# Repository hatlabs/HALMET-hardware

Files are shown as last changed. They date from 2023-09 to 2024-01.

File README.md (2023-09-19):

# Hat Labs Marine Engine/Tank Interface

This repository contains the Hat Labs Marine Engine/Tank Interface (HALMET) hardware design. HALMET is a powerful microcontroller development board designed for marine environments with a focus on engine and tank monitoring.

HALMET can be used to easily create different types of sensors and control devices for boats. Use scenarios include:

- RPM sensors
- tank level sensors
- bilge sensors
- Engine alarm sensors
- Engine temperature sensors

Since the board has native WiFi and NMEA 2000 compatible CAN bus connectivity, it can be used to create boards with either Signal K or native NMEA 2000 connectivity (or both!).

## Features

The main design features include:

- Built around ESP32, a powerful 32-bit microcontroller with 4 MB of flash
- Wide-range 6-32 V power input with surge protection
- NMEA 2000 compatible CAN interface (4-pin pluggable terminal block screw connector)
- 4 analog inputs with 0-32V input range and 16-bit resolution (2-pin pluggable terminal block screw connectors)
- 4 digital inputs with -32-32V input range, Schmitt triggered logic level threshold at 1.5V (2-pin pluggable terminal block screw connectors)
- 1-Wire interface (3-pin 2.54 mm header)
- I2C interface with both a SparkFun Qwiic connector and a 4-pin 2.54 mm header
- USB interface for programming and serial communication (USB Micro B)
- All above interfaces with proper electromagnetic compatibilty (EMC) design -- the device won't interfere with navigational devices or radio equipment
- All available general-purpose input/output (GPIO) pins broken out to a separate header
- Board designed to fit low-cost waterproof 100x68x50 mm enclosures

Rendering of a version 1.0.0 board:

<!--
Front side.
![Rev. 1.0.0 board](images/pcb_rev_2.0.0.jpg)

Back side.
![Rev. 1.0.0 board bottom side](images/pcb_rev_2.0.0-back.jpg)

-->

## Getting HALMET

HALMET will be available for purchase at the [Hat Labs web store](https://shop.hatlabs.fi/).

## Documentation

HALMET documentation will be available at the [project GitHub Pages](https://docs.hatlabs.fi/halmet/).

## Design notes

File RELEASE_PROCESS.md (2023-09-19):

# JLCPCB release process

## Prerequisites

The release process relies on a [jlc-kicad-tools](https://github.com/matthewlai/JLCKicadTools) script.

To install the script, apply the following commands:
    
    pip3 install git+https://github.com/matthewlai/JLCKicadTools
    pip3 install logzero==1.5.0

## Updating metadata

Create a new release branch, e.g. `release_0.2.0`.

Update page title block for both the schema and the layout (File -> Page Settings).

## Creating assembly files

Create assembly files:

### Eeschema

1. Tools -> Generate Bill of Materials
2. Select any BOM and click Generate (we only need the intermediate XML file).

### Pcbnew

1. File -> Plot -> Plot (Output folder "assembly", otherwise default settings are fine)
2. In the same dialog, Generate Drill Files -> Generate Drill File

3. File -> Fabrication Outputs -> Footprint Position File -> Generate Position File (single file)

### Modifying fabrication files for JLCPCB

On the command line:

    ./fix-jlcpcb-files.sh

## Creating the order

Go to jlcpcb.com -> Order now, and upload `assembly.zip` through the "Add your gerber file" button.

The gerber previewer doesn't always work. 
If that's the case, go to the JLCPCB website File Manager and click on Quote on the uploaded file (once the preview has rendered).

Apply the following selections:

- PCB Qty: (as you wish, there's an extra engineering fee above 10, though)
- Impedance: Yes, JLC7628
- PCB Color: green is usually fastest to manufacture
- Surface Finish: ENIG-RoHS (LeadFree HASL-RoHS might be ok)
- Confirm Production file is recommended
- Remove Order Number: Specify a location

Then select SMT Assembly.

- Assemble top side
- Tooling holes: as you like

Accept the terms and Confirm.

Add BOM File: upload `assembly/HALMET_bom_jlc.csv`
Add CPL File: upload `assembly/HALMET_cpl_jlc.csv`

Select Next.

Verify the parts. For HALMET, there should be only 1 part (the JST SH connector) not selected.
Go through the listing and check that the part type and footprint of uploaded BOM data match the matched part detail. 
This is boring but important!
If any of the parts are out of stock, find a replacement on [https://jlcpcb.com/parts](https://jlcpcb.com/parts) and update the schema and the layout and create fabrication files.
If you're absolutely certain that the layout didn't change, you can just re-upload the BOM and CPL files.

Next.

You're in part placement review.
In principle, JLCPCB pre-inspection catches misrotated parts and fixes the rotation, but I've had an IC be 180° misrotated once. 
So, better check.
The viewer doesn't always work.
If that happens, go back and click the next button again until you see the components.
Go through the layout carefully.

If any of the components are misaligned, check the footprint name in `assembly/HALMET_cpl_jlc.csv`.
Then modify the CPL DB (`cpl_rotations_db.csv`).
Add the footprint regex at the top of the file (but under the header line, of course) with the required rotation adjustment. 
Note that if the footprint matches an existing regex, the new regex should be more specific than the old one, and the rotation adjustment should be in relation to the old one. Note that positive degrees are to the counterclockwise.

If you had to modify the CPL DB, rerun the modification script and reupload the BOM and CPL files.

Once the footprint alignments are correct, you want to Download Unselected Parts list for ordering any missing components from LCSC or elsewhere.
Review the unselected parts list to ensure there are no accidental omissions!
You'll hate yourself if you don't!
Note that if you have assigned LCSC part numbers to the unselected parts, you can upload the file to the LCSC BOM tool to create an order for those parts.

Click "Save to Cart". 
You're done with creating the order.

## Updating the Git repo

After ordering the PCBs:

- Commit the changed files.
- Update the release process documentation, if needed!
- Create a new final commit for the assembly directory contents.
- Finally, create a PR against `main`. 
  This PR should _not_ include `assembly` directory, however. 
  We do not want to have the output files in the main branch.
- Merge the PR and you're done!

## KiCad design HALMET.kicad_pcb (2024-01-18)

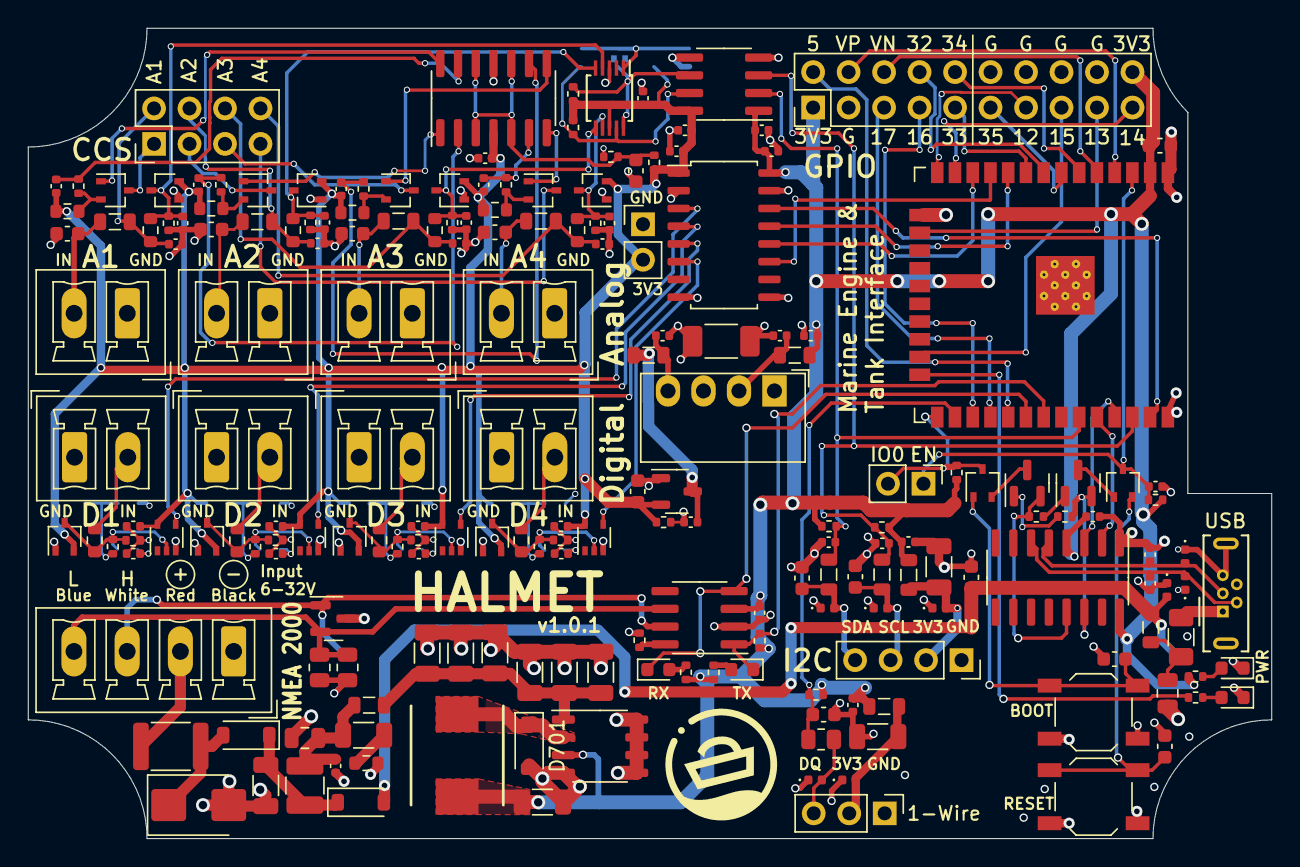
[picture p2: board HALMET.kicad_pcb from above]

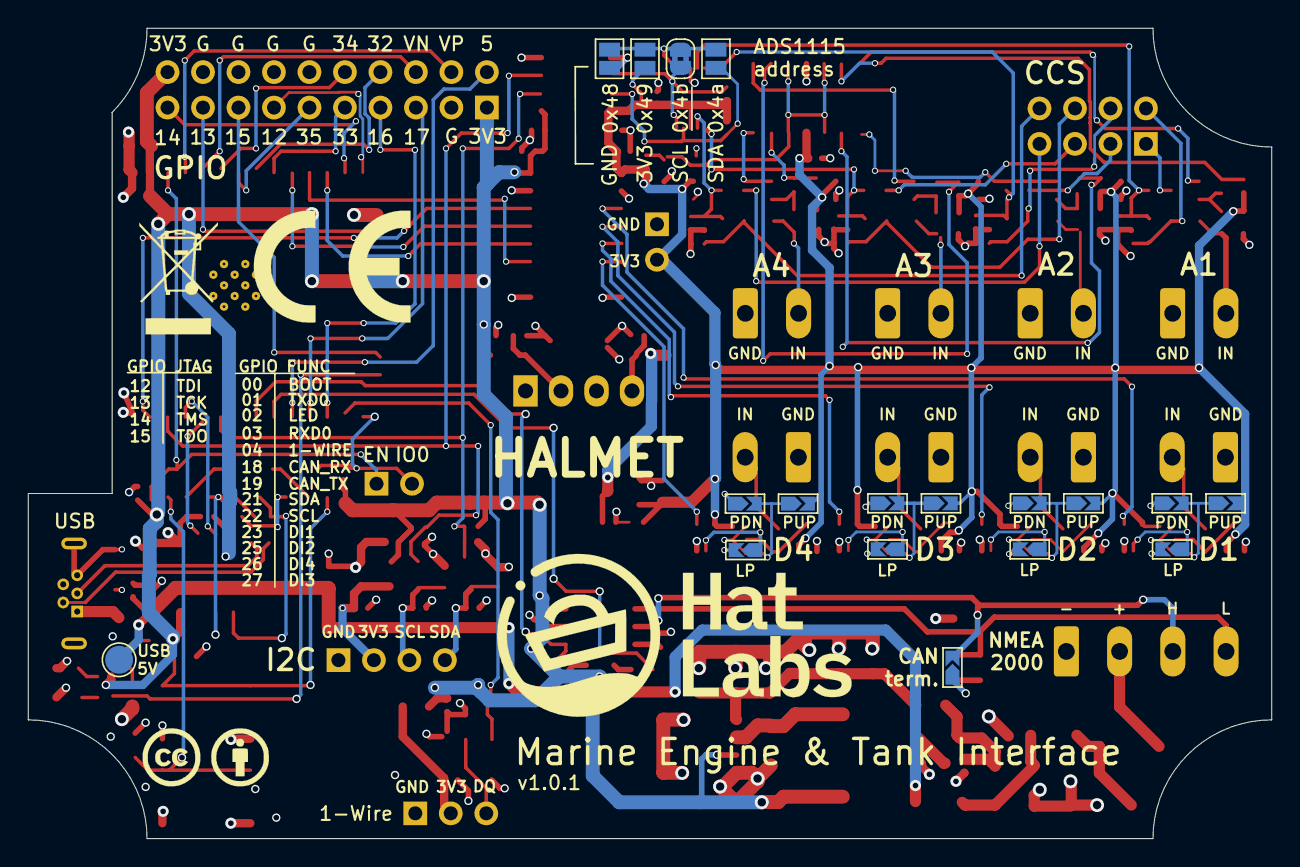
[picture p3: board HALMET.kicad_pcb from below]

Board: 4 copper layers, 89.0 x 58.0 mm, 222 parts (21 on the bottom side), 119 nets.

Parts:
C202: 22uF; C_0603_1608Metric
C203: 1uF; C_0402_1005Metric
C304: 47uF/6.3V; C_1206_3216Metric
C402: 4.7uF/16V; C_0603_1608Metric
C403, C404: 10pF/50V; C_0402_1005Metric
C501, C502: 100nF/50V; C_0603_1608Metric
C503, C715: 1uF/50V; C_0805_2012Metric
C601, C604, C612, C614, C705, C706: 33pF/50V; C_0603_1608Metric
C602, C606, C607, C608, C609, C610, C624, C901, C1113, C1114, C1115, C1116, C1204, C1205, C1206, C1207: 100nF; C_0402_1005Metric
C603, C605, C613, C615, C702, C703: 33pF; C_0402_1005Metric
C611: 68nF; C_0603_1608Metric
C620, C621, C622, C623: 10nF; C_0402_1005Metric
C701, C801: 10uF; C_0402_1005Metric
C704, C707, C708, C709, C710, C711, C712, C714, C803: 10uF/50V; C_1206_3216Metric
C713: 4.7nF/50V; C_0402_1005Metric
C716: 4.7uF/50V; C_1206_3216Metric
C802: 1nF/50V; C_0603_1608Metric
C1101, C1102, C1103, C1112: 3.3nF; C_0402_1005Metric
C1104, C1105, C1106, C1107: 220pF; R_0402_1005Metric
C1201, C1202, C1208, C1210: 4.7uF; C_0402_1005Metric
C1203: 10uF/10V; C_0603_1608Metric
C1209: 220pF/2kV; C_1808_4520Metric
D201, D303, D701: B5819W; D_SOD-123
D301: SMBJ33CA; D_SMB
D401, D402, D403, D503, D504, D903, D904, D905: ESD5451N; D_0402_1005Metric
D501: BLUE LED; LED_0603_1608Metric
D502: RED LED; LED_0603_1608Metric
D603, D604, D605, D611, D1103, D1104, D1105, D1113: BAT54S; SOT-323_SC-70
D801: SM24CANB; SOT-23
D1001, D1002: GREEN LED; LED_0603_1608Metric
D1101, D1102: BAT54A; SOT-323_SC-70
F301: mSMD050-60V; Fuse_1812_4532Metric
F401: BSMD1206-100-6V; Fuse_1206_3216Metric
FB401, FB701, FB704, FB801: GZ2012D601TF; L_0805_2012Metric
FB601, FB602, FB603, FB604, FB702, FB703: GZ2012D101TF; L_0805_2012Metric
G601: CC-BY; cc-by_5mm
G602: CE-logo; CE-Logo_11.2x8mm_SilkScreen
G605: HL-Logo; Hat_Labs_25.4mm
G701: HL-Pictogram; HaL_picto_8mm
H1001, H1002: MountingHole; MountingSlot_3.2mm_M3_Unplated
J201: GPIO; PinHeader_2x10_P2.54mm_Vertical
J203: Conn_01x01; TestPoint_Pad_D2.0mm
J302, J1201: Conn_01x02; PinHeader_1x02_P2.54mm_Vertical
J401: USB_B_Micro; USB_Micro-B_Wuerth_614105150721_Vertical
J602: Conn_02x04_Odd_Even; PinHeader_2x04_P2.54mm_Vertical
J604, J605, J606, J607, J1103, J1104, J1105, J1106: Conn_01x02; PhoenixContact_MCV_1,5_2-G-3.81_1x02_P3.81mm_Vertical
J702: Conn_01x04; PinSocket_1x04_P2.54mm_Vertical
J801: Conn_01x03; PinHeader_1x03_P2.54mm_Vertical
J802: Conn_01x04; PhoenixContact_MCV_1,5_4-G-3.81_1x04_P3.81mm_Vertical
JP601, JP1101, JP1102, JP1103, JP1104, JP1105, JP1106, JP1107, JP1108, JP1109, JP1110, JP1111, JP1112: SolderJumper_2_Open; SolderJumper-2_P1.3mm_Open_TrianglePad_Narrow
JP602, JP604, JP605: Open; SolderJumper-2_P1.3mm_Open_Pad1.0x1.5mm
JP603: Bridged; SolderJumper-2_P1.3mm_Bridged2Bar_RoundedPad1.0x1.5mm
L301: SMMS0650-470M; SMMS0650-1R0M
L701: NLCV32T-100K-EFR; L_1210_3225Metric
L1201, L1202: CMH201209B4R7MT; L_0805_2012Metric
PS1201: B0305S-1WR3; Converter_DCDC_Murata_MEE1SxxxxSC_THT
Q401, Q402: S8050; SOT-23
Q601, Q602, Q603, Q604: S9015; SOT-323_SC-70
R201, R213, R401, R402, R503, R612, R1103: 10k; R_0402_1005Metric
R501, R502, R701, R702, R1202, R1203: 2k; R_0402_1005Metric
R601, R602: 240R; R_0805_2012Metric
R603, R604, R605, R606, R611: 1k; R_0402_1005Metric
R607, R608, R609, R610: 30; R_0603_1608Metric
R613, R614, R616, R618, R1101, R1102, R1104, R1105: 20k; R_0603_1608Metric
R615, R617, R619, R621, R801: 2.2k; R_0402_1005Metric
R703: 4.7R; R_0603_1608Metric
R802: 100R; R_0805_2012Metric
R1001, R1002: 1.5k; R_0402_1005Metric
R1106, R1107, R1108, R1109: 100k; R_0402_1005Metric
R1201: 330R; R_0402_1005Metric
SW501, SW502: SW_Push; SW_SPST_TL3342
U201: ESP32-WROOM-32E-N16; ESP32-WROOM-32
U202: XL1509-3.3; SOP-8_3.9x4.9mm_P1.27mm
U401: CH340C; SOIC-16_3.9x9.9mm_P1.27mm
U501: SN65HVD230DR; SOIC-8_3.9x4.9mm_P1.27mm
U601: LMV324; SOIC-14_3.9x8.7mm_P1.27mm
U602: ADS1115IDGS; TSSOP-10_3x3mm_P0.5mm
U1101, U1102, U1103, U1104: 74LVC1G17; SOT-353_SC-70-5
U1201: π140U30; SOIC-16_4.55x10.3mm_P1.27mm
U1202: ISO1540; SOIC-8_3.9x4.9mm_P1.27mm
U1203: XC6206P332MR; SOT-23-3

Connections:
+3.3V: C202.2, C304.1, C602.1, C701.1, C801.1, C901.1, C1201.1, C1206.1, C1207.1, FB701.2, FB801.2, J201.1, J201.20, L301.2, L1201.1, R201.1, R213.1, R502.1, R701.2, R702.2, R801.2, R1001.1, R1002.1, R1103.1, U201.2 (VDD), U202.3 (FB), U401.4 (V3), U401.16 (VCC), U501.3 (VCC), U1201.16 (VDD2), U1202.1 (VCC1)
+3.3V_1: C606.2, C607.2, C608.2, C609.2, C610.1, C624.1, C1113.1, C1114.1, C1115.1, C1116.1, C1203.1, C1204.1, C1205.1, D603.2 (K), D604.2 (K), D605.2 (K), D611.2 (K), D1103.2 (K), D1104.2 (K), D1105.2 (K), D1113.2 (K), J1201.2, JP602.2 (B), JP1106.2 (B), JP1107.2 (B), JP1109.2 (B), JP1111.2 (B), R607.1, R608.1, R609.1, R610.1, R611.1, R1201.1, R1202.2, R1203.2, U601.4 (V+), U602.8 (VDD), U1101.5 (VCC), U1102.5 (VCC), U1103.5 (VCC), U1104.5 (VCC), U1201.1 (VDD1), U1202.8 (VCC2), U1203.2 (VOUT)
/Analog input/ADC_A1: C620.1, D611.3 (COM), R613.1, R621.2, U602.4 (AIN0)
/Analog input/ADC_A2: C621.1, D603.3 (COM), R614.1, R615.2, U602.5 (AIN1)
/Analog input/ADC_A3: C622.1, D604.3 (COM), R616.1, R617.2, U602.6 (AIN2)
/Analog input/ADC_A4: C623.1, D605.3 (COM), R618.1, R619.2, U602.7 (AIN3)
/Analog input/ADDR: JP602.1 (A), JP603.1 (A), JP604.1 (A), JP605.1 (A), U602.1 (ADDR)
/Analog input/INA1: C601.1, FB601.1, J606.2
/Analog input/INA2: C604.1, FB602.1, J604.2
/Analog input/INA3: C612.1, FB603.1, J605.2
/Analog input/INA4: C614.1, FB604.1, J607.2
/Analog input/INFA1: C603.1, FB601.2, J602.2, R613.2
/Analog input/INFA2: C605.1, FB602.2, J602.4, R614.2
/Analog input/INFA3: C613.1, FB603.2, J602.6, R616.2
/Analog input/INFA4: C615.1, FB604.2, J602.8, R618.2
/Analog input/IoutA1: J602.1, Q601.3 (C)
/Analog input/IoutA2: J602.3, Q602.3 (C)
/Analog input/IoutA3: J602.5, Q603.3 (C)
/Analog input/IoutA4: J602.7, Q604.3 (C)
/Analog input/QBA1: Q601.1 (B), U601.14
/Analog input/QBA2: Q602.1 (B), U601.1
/Analog input/QBA3: Q603.1 (B), U601.8
/Analog input/QBA4: Q604.1 (B), U601.7
/Analog input/SCL: JP603.2 (B), R1203.1, U602.10 (SCL), U1202.6 (SCL2)
/Analog input/SDA: JP604.2 (B), R1202.1, U602.9 (SDA), U1202.7 (SDA2)
/Analog input/Vin: C611.1, R611.2, R612.1, U601.3 (+), U601.5 (+), U601.10 (+), U601.12 (+)
/BOOT_AUTO: D1101.2, Q402.3 (C)
/BOOT_KEY: C501.1, D1101.1, SW501.2
/CAN_H: D801.1 (A1), J802.3, JP601.2 (B), U501.7 (CANH)
/CAN_L: D801.2 (A2), J802.4, R601.2, R602.2, U501.6 (CANL)
/CAN_RX: D1001.1 (K), U201.30 (IO18), U501.4 (R)
/CAN_TX: D1002.1 (K), R213.2, U201.31 (IO19), U501.1 (D)
/DI1: U201.37 (IO23), U1201.14 (VOA)
/DI2: U201.10 (IO25), U1201.13 (VOB)
/DI3: U201.12 (IO27), U1201.12 (VOC)
/DI4: U201.11 (IO26), U1201.11 (VOD)
/DQ: C802.1, R801.1, R802.1, U201.26 (IO4)
/Digital input/DigIn1: U1101.4, U1201.3 (VIA)
/Digital input/DigIn2: U1102.4, U1201.4 (VIB)
/Digital input/DigIn3: U1103.4, U1201.5 (VIC)
/Digital input/DigIn4: U1104.4, U1201.6 (VID)
/Digital input/In1: J1103.2, R1101.2
/Digital input/In2: J1104.2, R1102.2
/Digital input/In3: J1105.2, R1104.2
/Digital input/In4: J1106.2, R1105.2
/Digital input/Inp1: C1104.1, D1113.3 (COM), JP1101.1 (A), R1101.1, R1106.2, U1101.2
/Digital input/Inp2: C1105.1, D1103.3 (COM), JP1102.1 (A), R1102.1, R1107.2, U1102.2
/Digital input/Inp3: C1106.1, D1104.3 (COM), JP1103.1 (A), R1104.1, R1108.2, U1103.2
/Digital input/Inp4: C1107.1, D1105.3 (COM), JP1104.1 (A), R1105.1, R1109.2, U1104.2
/ESP32/EN: C203.1, D1102.3, J302.1, R201.2, U201.3 (EN)
/ESP32/IO0: D1101.3, J302.2, R1103.2, U201.25 (IO0)
/ESP32/IO5: J201.2, U201.29 (IO5)
/ESP32/IO16: J201.7, U201.27 (IO16)
/ESP32/IO17: J201.5, U201.28 (IO17)
/ESP32/IO32: J201.8, U201.8 (IO32)
/ESP32/IO33: J201.9, U201.9 (IO33)
/ESP32/IO34: J201.10, U201.6 (IO34)
/ESP32/IO35: J201.11, U201.7 (IO35)
/ESP32/SENSOR_VN: J201.6, U201.5 (SENSOR_VN)
/ESP32/SENSOR_VP: J201.4, U201.4 (SENSOR_VP)
/ESP32/TCK: J201.17, U201.16 (IO13)
/ESP32/TDI: J201.13, U201.14 (IO12)
/ESP32/TDO: J201.15, U201.23 (IO15)
/ESP32/TMS: J201.19, U201.13 (IO14)
/I2C/I2C_3V3: C704.1, D403.2 (A2), FB701.1, J702.2
/I2C/SCL_CONN: C706.1, D402.2 (A2), FB703.1, J702.3
/I2C/SDA_CONN: C705.1, D401.2 (A2), FB702.1, J702.4
/Isolation barrier/5V_unreg: C1202.1, L1202.2, U1203.3 (VIN)
/Isolation barrier/Vin_: C1208.1, L1201.2, PS1201.2 (+Vin)
/Isolation barrier/Vout_: C1210.1, L1202.1, PS1201.4 (+Vout)
/LED: R501.1, U201.24 (IO2)
/Onewire/DQ_CONN: D503.2 (A2), J801.3, R802.2
/Onewire/Onewire_3V3: C803.1, D504.2 (A2), FB801.1, J801.2
/Power input/CAN_+: F301.2, J802.2
/Power input/IN: C707.1, C708.1, C709.1, C710.1, C711.1, C712.1, FB704.1, U202.1 (IN)
/Power input/SW: D701.1 (K), L301.1, U202.2 (SW)
/Power input/Vin_fused: D301.1 (A1), D303.2 (A), F301.1
/Power input/Vin_protected: C714.2, D201.1 (K), D303.1 (K), L701.1
/RESET_AUTO: D1102.1, Q401.3 (C)
/RESET_KEY: C502.1, D1102.2, SW502.2
/SCL: C703.1, FB703.2, R702.1, U201.36 (IO22), U1202.3 (SCL1)
/SDA: C702.1, FB702.2, R701.1, U201.33 (IO21), U1202.2 (SDA1)
/USB/DTR: Q402.2 (E), R401.1, U401.13 (~DTR)
/USB/RTS: Q401.2 (E), R402.1, U401.14 (~RTS)
/USB/USB_D+: C403.1, D904.2 (A2), J401.3 (D+), U401.5 (UD+)
/USB/USB_D-: C404.1, D905.2 (A2), J401.2 (D-), U401.6 (UD-)
/USB/VBUS: F401.2, J401.1 (VBUS)
/USB_RXD: U201.35 (TXD0/IO1), U401.3 (RXD)
/USB_TXD: U201.34 (RXD0/IO3), U401.2 (TXD)
GND: C202.1, C203.2, C304.2, C402.2, C403.2, C404.2, C501.2, C502.2, C503.2, C602.2, C701.2, C702.2, C703.2, C704.2, C705.2, C706.2, C707.2, C708.2, C709.2, C710.2, C711.2, C712.2, C713.2, C714.1, C715.1, C801.2, C802.2, C803.2, C901.2, C1201.2, C1206.2, C1207.2, C1208.2, C1209.1, D301.2 (A2), D401.1 (A1), D402.1 (A1), D403.1 (A1), D501.1 (K), D502.1 (K), D503.1 (A1), D504.1 (A1), D701.2 (A), D801.3 (common), D903.1 (A1), D904.1 (A1), D905.1 (A1), J201.3, J201.12, J201.14, J201.16, J201.18, J401.5 (GND), J401.6 (Shield), J702.1, J801.1, J802.1, PS1201.1 (-Vin), R503.2, R703.1, SW501.1, SW502.1, U201.1 (GND), U201.15 (GND), U201.38 (GND), U201.39 (GND), U202.4 (~EN), U202.5 (GND), U202.6 (GND), U202.7 (GND), U202.8 (GND), U401.1 (GND), U501.2 (GND), U1201.9 (GND2), U1201.15 (GND2), U1202.4 (GND1)
GND1: C601.2, C603.2, C604.2, C605.2, C610.2, C611.2, C612.2, C613.2, C614.2, C615.2, C620.2, C621.2, C622.2, C623.2, C624.2, C1101.2, C1102.2, C1103.2, C1104.2, C1105.2, C1106.2, C1107.2, C1112.2, C1113.2, C1114.2, C1115.2, C1116.2, C1202.2, C1203.2, C1204.2, C1205.2, C1209.2, C1210.2, D603.1 (A), D604.1 (A), D605.1 (A), D611.1 (A), D1103.1 (A), D1104.1 (A), D1105.1 (A), D1113.1 (A), J604.1, J605.1, J606.1, J607.1, J1103.1, J1104.1, J1105.1, J1106.1, J1201.1, JP605.2 (B), JP1105.1 (A), JP1108.1 (A), JP1110.1 (A), JP1112.1 (A), PS1201.3 (-Vout), R612.2, R615.1, R617.1, R619.1, R621.1, R1201.2, U601.11 (V-), U602.3 (GND), U1101.3 (GND), U1102.3 (GND), U1103.3 (GND), U1104.3 (GND), U1201.2 (GND1), U1201.8 (GND1), U1202.5 (GND2), U1203.1 (GND)
unnamed: C503.1, F401.1, FB401.2
unnamed: C713.1, C715.2, C716.1, FB704.2, L701.2
unnamed: C716.2, R703.2
unnamed: D501.2 (A), R501.2
unnamed: D502.2 (A), R502.2
unnamed: D1001.2 (A), R1001.2
unnamed: D1002.2 (A), R1002.2
unnamed: JP601.1 (A), R601.1, R602.1
unnamed: C1112.1, JP1101.2 (B)
unnamed: C1101.1, JP1102.2 (B)
unnamed: C1102.1, JP1103.2 (B)
unnamed: C1103.1, JP1104.2 (B)
unnamed: JP1105.2 (B), JP1106.1 (A), R1106.1
unnamed: JP1107.1 (A), JP1108.2 (B), R1107.1
unnamed: JP1109.1 (A), JP1110.2 (B), R1108.1
unnamed: JP1111.1 (A), JP1112.2 (B), R1109.1
unnamed: Q401.1 (B), R401.2
unnamed: Q402.1 (B), R402.2
unnamed: Q601.2 (E), R603.1, R607.2
unnamed: Q602.2 (E), R604.1, R608.2
unnamed: Q603.2 (E), R605.1, R609.2
unnamed: Q604.2 (E), R606.1, R610.2
unnamed: R503.1, U501.8 (Rs)
unnamed: C607.1, R604.2, U601.2 (-)
unnamed: C609.1, R606.2, U601.6 (-)
unnamed: C608.1, R605.2, U601.9 (-)
unnamed: C606.1, R603.2, U601.13 (-)
USB_5V: C402.1, D201.2 (A), D903.2 (A2), FB401.1, J203.1

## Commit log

2023-09-19 HALMET redesign
    [ESP32.kicad_sch, HALMET.kicad_sch, I2C.kicad_sch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]
2023-09-19 Substitute parts according to availability
    [ESP32.kicad_sch, analog_input.kicad_sch, isolation.kicad_sch]
2023-11-28 Implement HALMET v1.0.0 design changes
    [ESP32.kicad_sch, HALMET.kicad_pcb, HALMET.kicad_sch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]
2023-12-05 Update parts according to availability
    [ESP32.kicad_sch, HALMET.kicad_pcb, power-input.kicad_sch]
2024-01-05 Fix DI4 & DI3 pins
    [ESP32.kicad_sch, HALMET.kicad_pcb, HALMET.kicad_sch]
2024-01-18 Version 1.0.1 changes
    - Add a power header to isolated side
    - Fix GPIO silk screen bugs
    - Add labels for isolated I2C pads
    - Bump version to 1.0.1
    [ESP32.kicad_sch, HALMET.kicad_pcb, HALMET.kicad_sch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]
2025-09-01 Save with a newer KiCad; change parts for availability; fix rotations
    [ESP32.kicad_sch, HALMET.kicad_sch, I2C.kicad_sch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]

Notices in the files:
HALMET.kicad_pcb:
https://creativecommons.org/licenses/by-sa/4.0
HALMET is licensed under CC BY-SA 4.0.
